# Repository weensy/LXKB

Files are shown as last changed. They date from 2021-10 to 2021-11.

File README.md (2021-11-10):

<p align="center">
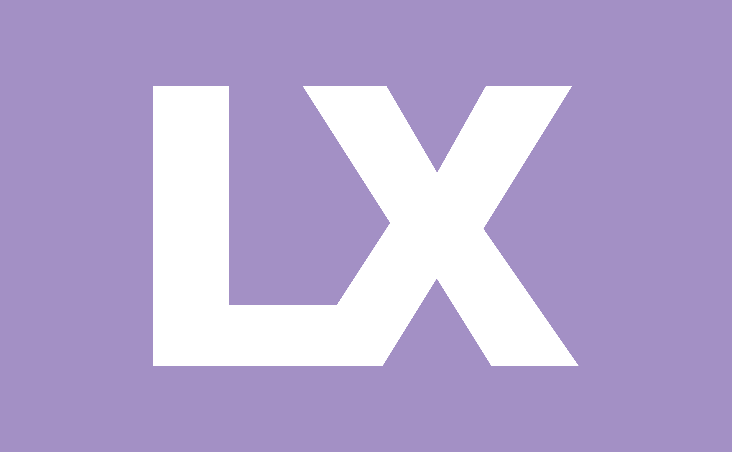
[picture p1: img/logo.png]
LXKB Logo

<p>
<h2 align="center">60% Mechanical Keyboard</h1>
  
LXKB is an open-source project that makes minimal keyboard with 60 keys.

# Introduction

### Who is it for?
For coders, writers and for everyone.  
This allows for fast typing with minimal movement.
In addition, it minimizes the burden on the shoulder even for long time use.
You should use a minimal keyboard for shoulder health.
A 60% keyboard is best for that.  
So, is LXKB different from the normal 60% keyboard?
It's in the aesthetics of this keyboard.

### Aesthetics
is realized in Symmetry.  
The following is the layout of LXKB for Windows. *[*see more layouts](layout.md)*
<p align="center">
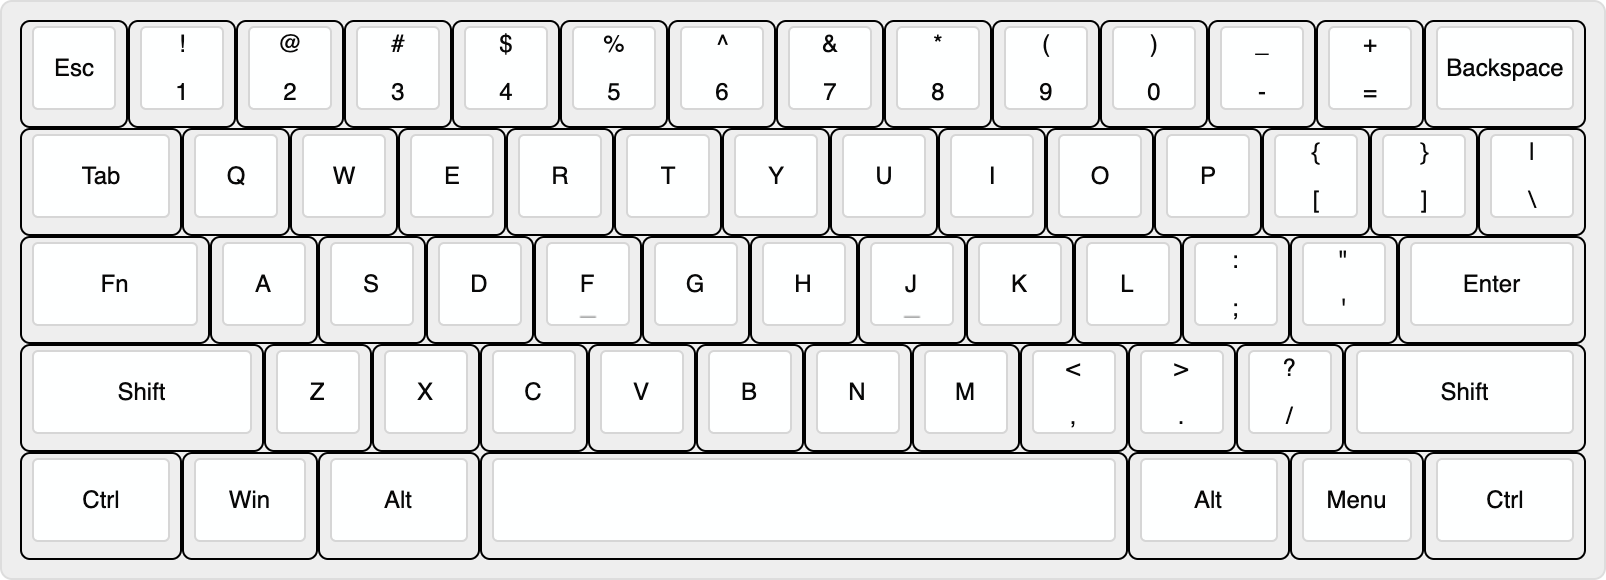
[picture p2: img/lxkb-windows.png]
LXKB for Windows

<p>

It is a completely symmetrical design.  
Draw a line in the center:
<p align="center">
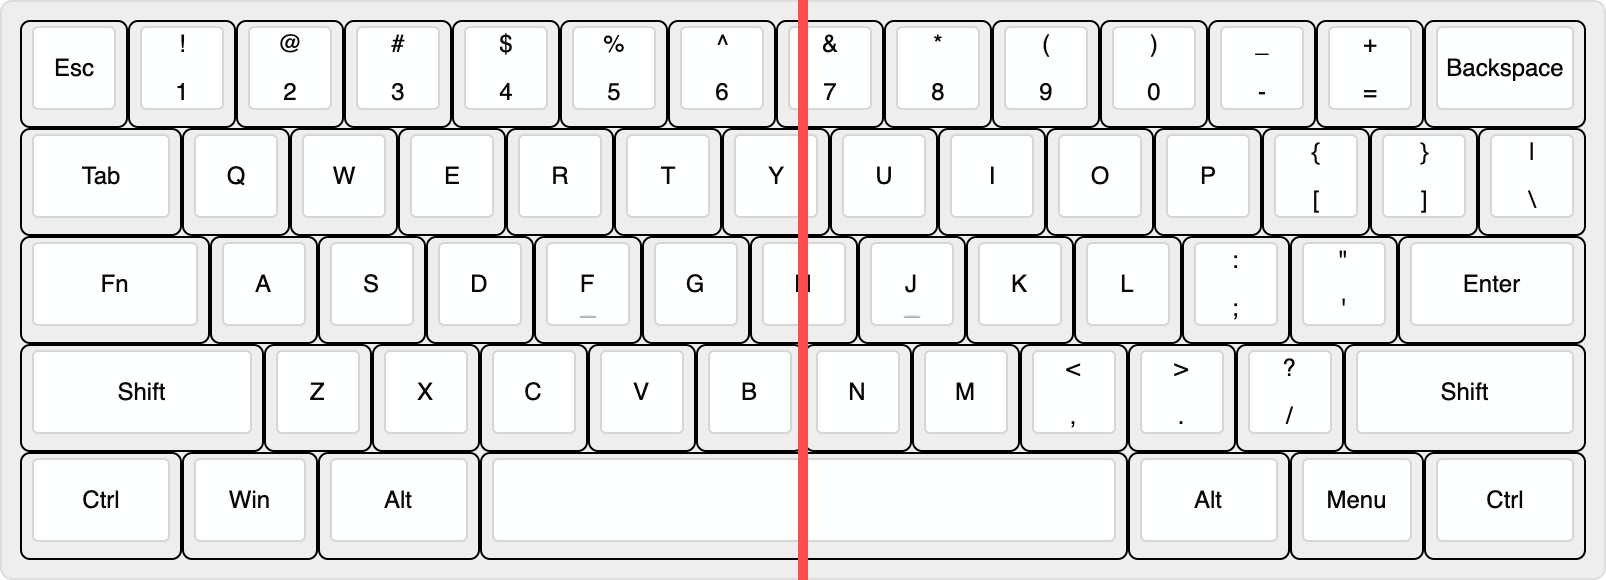
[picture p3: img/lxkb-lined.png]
LXKB center lined

<p>

Row 1, 2 are diagonally symmetric. And row 3 to 5 are perfectly symmetrical.
As is known, most people feel psychologically secure in symmetry.

### Feature
The most striking feature is the position of the Fn key.
The usage of Caps lock is very infrequent. But among the non-letter keys, it is located in the most convenient place to press. This place is a waste for Caps lock! It is why we put Fn key here.  
We have placed the rest of combination keys where comfortable to press.
People place their hands diagonally on the keyboard for body structural reasons. Therefore, the range of keys that can be pressed by moving only a finger from the default position is as follow:
<p align="center">
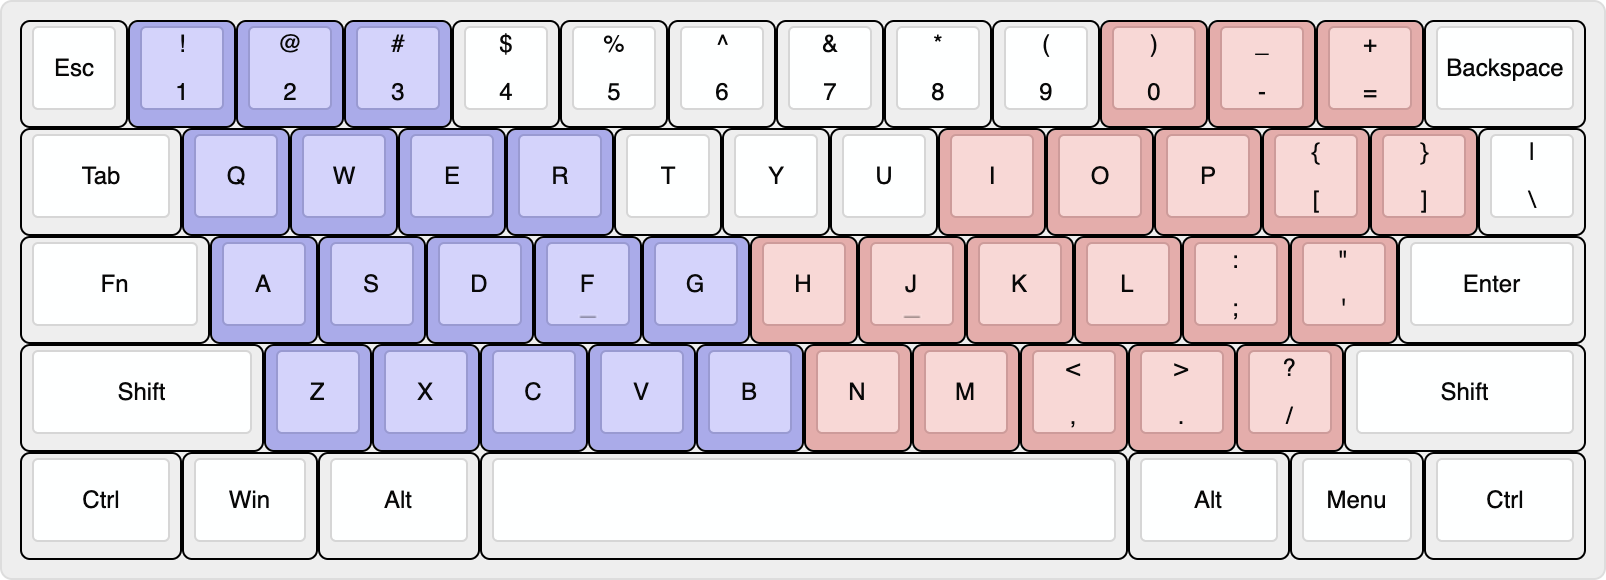
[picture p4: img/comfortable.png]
Comfortable range

<p>
Blue is left hand, red is right hand. Since the left hand presses the Fn key, the combination keys are placed in the red range. Here is the result:
<p align="center">
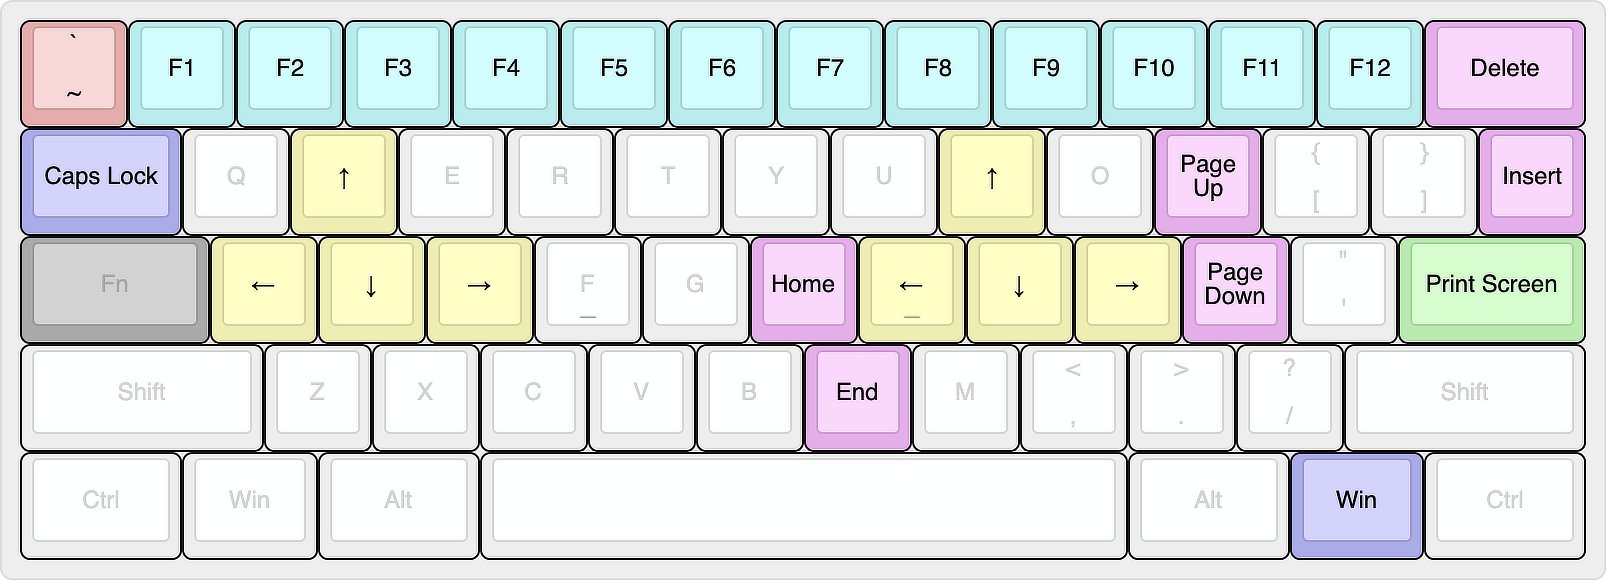
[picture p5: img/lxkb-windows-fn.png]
LXKB for Windows - Fn

<p>

### Inspired by
This layout is inspried by [these keyboards](./inspired.md).

### Keycaps
This layout is not standard, so be careful when buying keycaps.  
[Here](./keycaps.md) is a list of compatible keycap sets.

# Goals
We want to provide sources for making keyboards that is:
- Gerber files for ordering PCB
- Draw files for ordering Case
- Keymap.json file for QMK Configurator
- Documentation for ordering, assembly and setting from zero to finished product

# Contribute
Do you want to help? That’s awesome. We welcome contributions of all kinds from everyone.

# Open-source
The following open-source software was used for this project. Thanks for everything:
- [Keyboard Layout Editor](http://www.keyboard-layout-editor.com/)
- [Keyboard tools](http://keyboard-tools.xyz/)
- [Freerouting](https://github.com/freerouting/freerouting)

# License
Licensed under the [CC BY-NC-SA 4.0](./LICENSE).  
Almost everything is permitted, but not for commercial use.

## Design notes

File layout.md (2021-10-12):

# Layouts of LXKB
> These were made using [keyboard-layout-editor.com](http://www.keyboard-layout-editor.com/)

- [LXKB for Windows](http://www.keyboard-layout-editor.com/#/gists/499662763cf8b9fc48e7f24f23e9895a)
<p align="center">
LXKB for Windows
<p>

- [LXKB for Windows - Fn combined](http://www.keyboard-layout-editor.com/#/gists/9ed083197440aef61fcd359ec48cc0b2)
<p align="center">
LXKB for Windows
<p>

- [LXKB for MacOS](http://www.keyboard-layout-editor.com/#/gists/e5a1952ee05224aab8b0ef7e21352cde)
<p align="center">
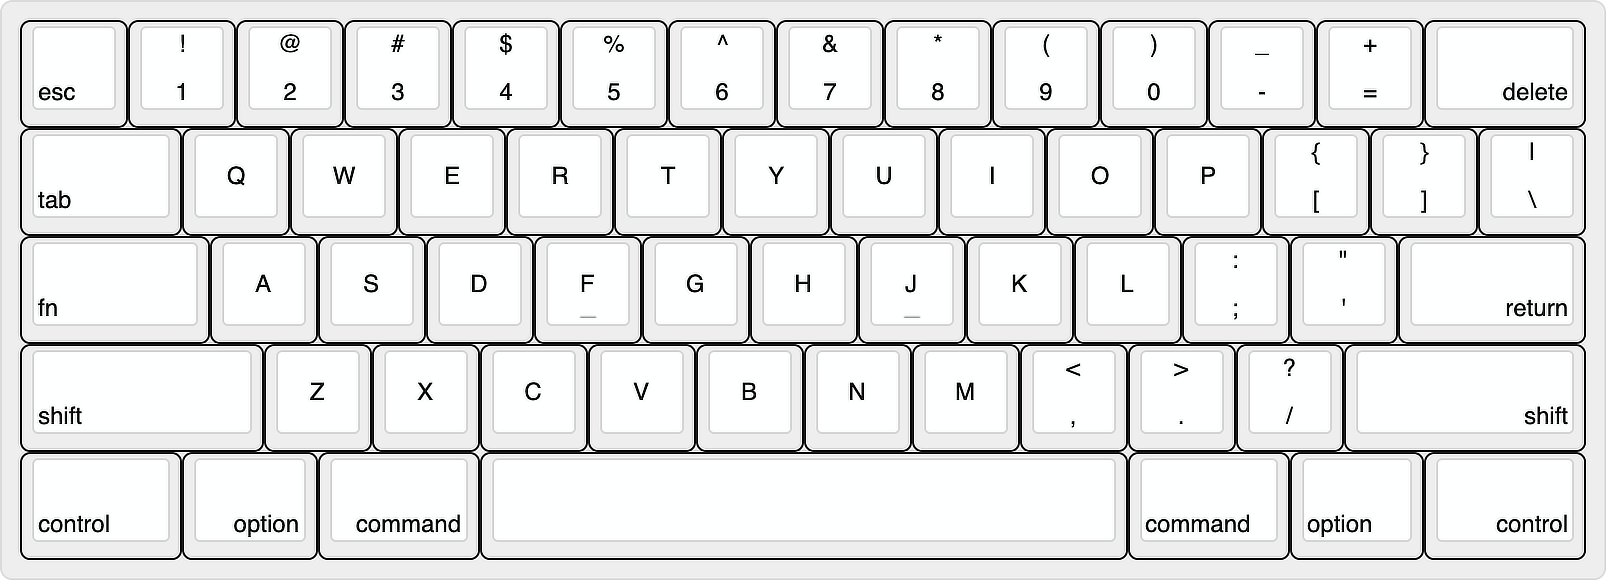
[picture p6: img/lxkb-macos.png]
LXKB for Windows

<p>

- [LXKB for MacOS - Fn combined](http://www.keyboard-layout-editor.com/#/gists/0dadb3639b67f5e03f305343836615cb)
<p align="center">
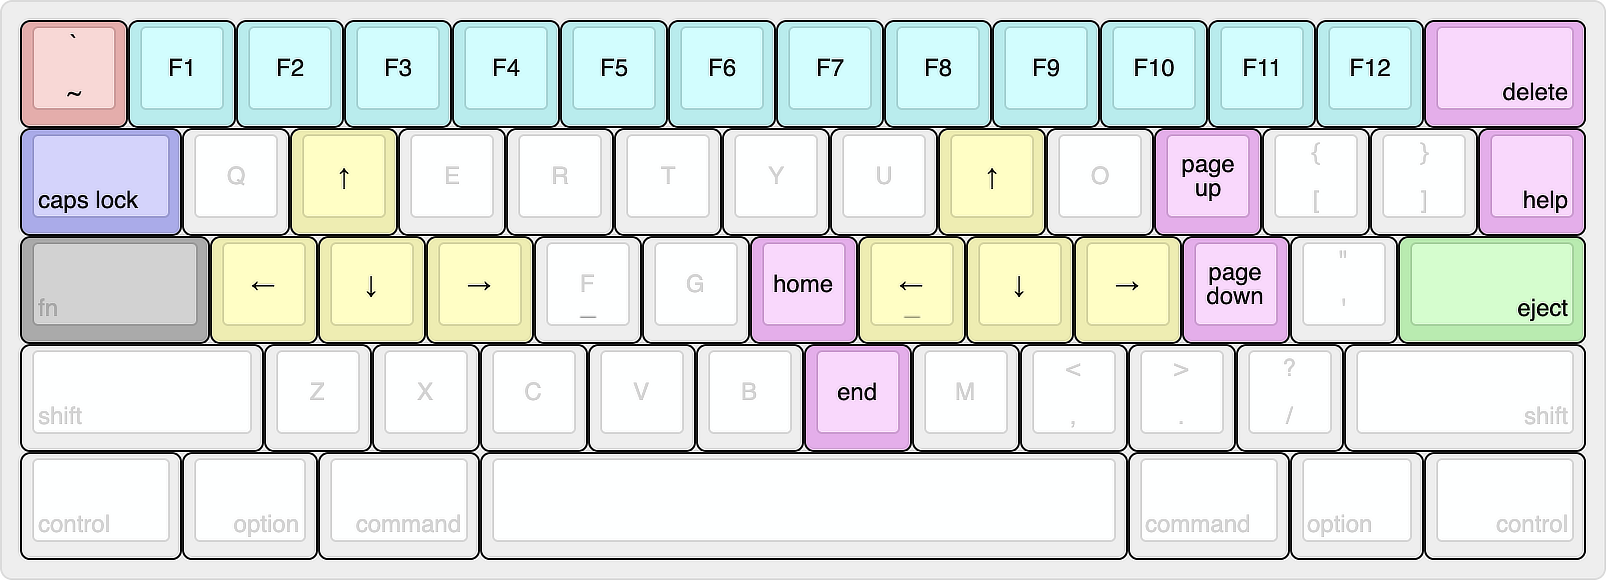
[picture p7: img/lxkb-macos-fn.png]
LXKB for Windows

<p>

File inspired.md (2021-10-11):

The LXKB's layout is inspired by old Apple keyboards.

## Apple M0110
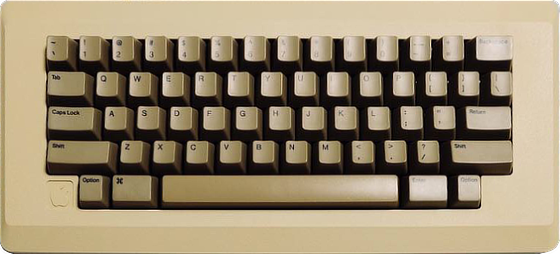
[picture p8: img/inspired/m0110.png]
M0110

- [image source](https://coolenjoy.net/bbs/34/2232320?sst=wr_hit&sod=desc&sop=and&page=4853)

## Apple M0115
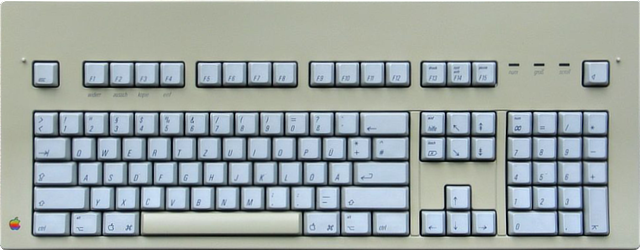
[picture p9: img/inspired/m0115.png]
M0115

- [image source](http://www.mauseum.net/Tastatura/)

## NeXT keyboard
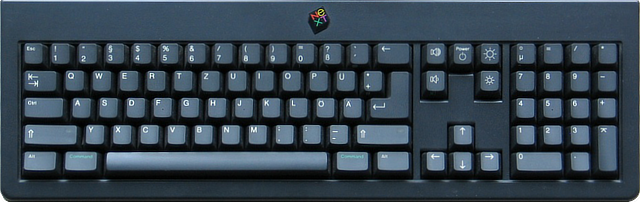
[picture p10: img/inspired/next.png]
NeXT

- [image source](http://www.mauseum.net/Tastatura/)

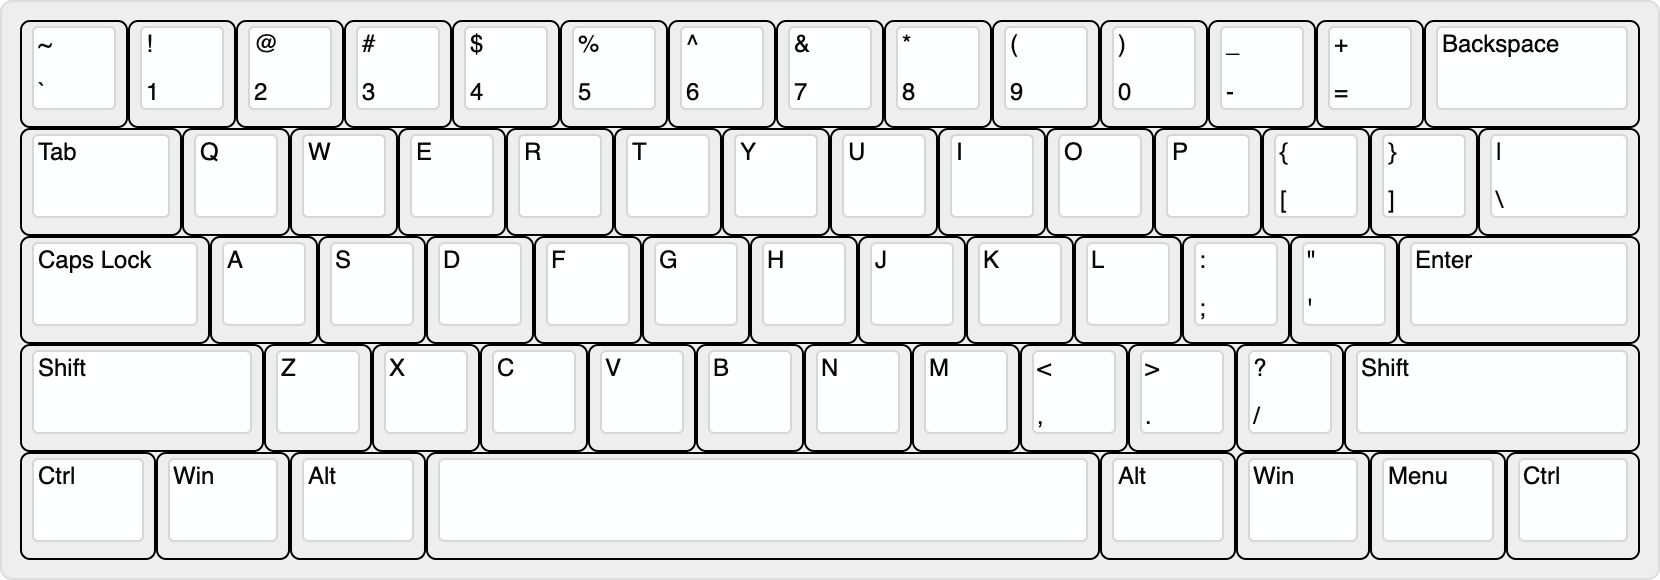
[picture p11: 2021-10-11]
img/default60.png

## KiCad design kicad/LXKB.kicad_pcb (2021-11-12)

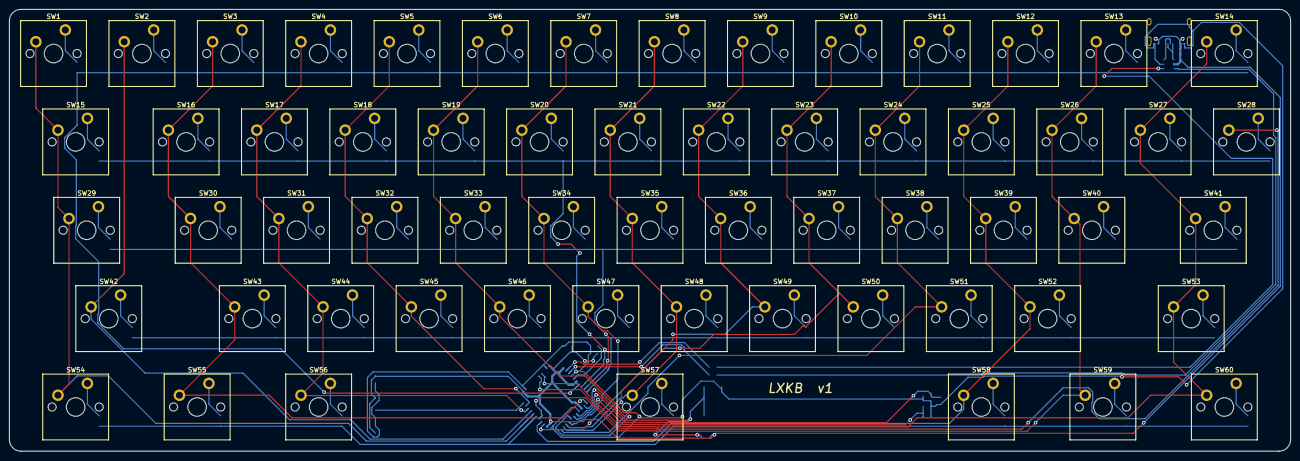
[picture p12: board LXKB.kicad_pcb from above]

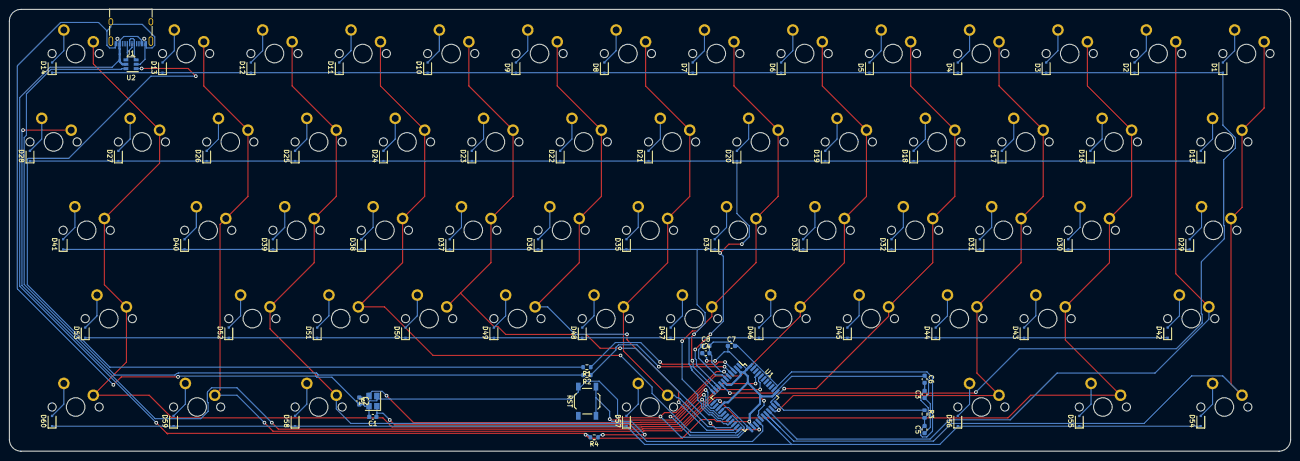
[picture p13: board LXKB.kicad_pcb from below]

Board: 2 copper layers, 276.2 x 95.2 mm, 137 parts (77 on the bottom side), 93 nets.

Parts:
C1, C2: 22p; C_0603_1608Metric
C3, C4, C5, C6: 0.1u; C_0603_1608Metric
C7: 4.7u; C_0603_1608Metric
C8: 1u; C_0603_1608Metric
D1, D2, D3, D4, D5, D6, D7, D8, D9, D10, D11, D12, D13, D14, D15, D16, D17, D18, D19, D20, D21, D22, D23, D24, D25, D26, D27, D28, D29, D30, D31, D32, D33, D34, D35, D36, D37, D38, D39, D40, D41, D42, D43, D44, D45, D46, D47, D48, D49, D50, D51, D52, D53, D54, D55, D56, D57, D58, D59, D60: D; D_SOD-323F
J1: USB_C_Receptacle_USB2.0; USB_C_Receptacle_XKB_U262-16XN-4BVC11
R1, R2: 22; R_0603_1608Metric
R3, R4: 10k; R_0603_1608Metric
RST: SW_SPST; SW_SPST_TL3342
SW1, SW2, SW3, SW4, SW5, SW6, SW7, SW8, SW9, SW10, SW11, SW12, SW13, SW16, SW17, SW18, SW19, SW20, SW21, SW22, SW23, SW24, SW25, SW26, SW27, SW28, SW30, SW31, SW32, SW33, SW34, SW35, SW36, SW37, SW38, SW39, SW40, SW43, SW44, SW45, SW46, SW47, SW48, SW49, SW50, SW51, SW52: SW_Push; SW_Cherry_MX_PCB_1.00u
SW14, SW15, SW54, SW56, SW58, SW60: SW_Push; SW_Cherry_MX_PCB_1.50u
SW29, SW41: SW_Push; SW_Cherry_MX_PCB_1.75u
SW42, SW53: SW_Push; SW_Cherry_MX_PCB_2.25u
SW55, SW59: SW_Push; SW_Cherry_MX_PCB_1.25u
SW57: SW_Push; SW_Cherry_MX_PCB_6.00u
U1: ATmega16U4-AU; TQFP-44_10x10mm_P0.8mm
U2: TPD2S017; SOT-23-6
Y1: Crystal_GND24; Crystal_SMD_3225-4Pin_3.2x2.5mm

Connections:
COL0: SW1.1, SW15.1, SW29.1, SW54.1, U1.29
COL1: SW2.1, SW42.1, U1.30
COL2: SW3.1, SW16.1, SW30.1, SW43.1, SW55.1, U1.12
COL3: SW4.1, SW17.1, SW31.1, SW44.1, SW56.1, U1.31
COL4: SW5.1, SW18.1, SW32.1, SW45.1, U1.32
COL5: SW6.1, SW19.1, SW33.1, SW46.1, U1.18
COL6: SW7.1, SW20.1, SW34.1, SW47.1, U1.19
COL7: SW8.1, SW21.1, SW35.1, SW48.1, SW57.1, U1.20
COL8: SW9.1, SW22.1, SW36.1, SW49.1, U1.21
COL9: SW10.1, SW23.1, SW37.1, SW50.1, U1.25
COL10: SW11.1, SW24.1, SW38.1, SW51.1, U1.22
COL11: SW12.1, SW25.1, SW39.1, SW52.1, SW58.1, U1.26
COL12: SW13.1, SW26.1, SW40.1, SW59.1, U1.27
COL13: SW14.1, SW27.1, SW41.1, SW53.1, SW60.1, U1.41
COL14: SW28.1, U1.40
GND: C1.2, C2.2, C3.2, C4.2, C5.2, C6.2, C7.2, C8.2, J1.A1, J1.A12, J1.B1, J1.B12, J1.S1, R3.2, RST.1, U1.5, U1.15, U1.23, U1.35, U1.43, U2.2, Y1.2, Y1.4
unnamed: D1.2, SW1.2
unnamed: D2.2, SW2.2
unnamed: D3.2, SW3.2
unnamed: D4.2, SW4.2
unnamed: D5.2, SW5.2
unnamed: D6.2, SW6.2
unnamed: D7.2, SW7.2
unnamed: D8.2, SW8.2
unnamed: D9.2, SW9.2
unnamed: D10.2, SW10.2
unnamed: D11.2, SW11.2
unnamed: D12.2, SW12.2
unnamed: D13.2, SW13.2
unnamed: D14.2, SW14.2
unnamed: D15.2, SW15.2
unnamed: D16.2, SW16.2
unnamed: D17.2, SW17.2
unnamed: D18.2, SW18.2
unnamed: D19.2, SW19.2
unnamed: D20.2, SW20.2
unnamed: D21.2, SW21.2
unnamed: D22.2, SW22.2
unnamed: D23.2, SW23.2
unnamed: D24.2, SW24.2
unnamed: D25.2, SW25.2
unnamed: D26.2, SW26.2
unnamed: D27.2, SW27.2
unnamed: D28.2, SW28.2
unnamed: D29.2, SW29.2
unnamed: D30.2, SW30.2
unnamed: D31.2, SW31.2
unnamed: D32.2, SW32.2
unnamed: D33.2, SW33.2
unnamed: D34.2, SW34.2
unnamed: D35.2, SW35.2
unnamed: D36.2, SW36.2
unnamed: D37.2, SW37.2
unnamed: D38.2, SW38.2
unnamed: D39.2, SW39.2
unnamed: D40.2, SW40.2
unnamed: D41.2, SW41.2
unnamed: D42.2, SW42.2
unnamed: D43.2, SW43.2
unnamed: D44.2, SW44.2
unnamed: D45.2, SW45.2
unnamed: D46.2, SW46.2
unnamed: D47.2, SW47.2
unnamed: D48.2, SW48.2
unnamed: D49.2, SW49.2
unnamed: D50.2, SW50.2
unnamed: D51.2, SW51.2
unnamed: D52.2, SW52.2
unnamed: D53.2, SW53.2
unnamed: D54.2, SW54.2
unnamed: D55.2, SW55.2
unnamed: D56.2, SW56.2
unnamed: D57.2, SW57.2
unnamed: D58.2, SW58.2
unnamed: D59.2, SW59.2
unnamed: D60.2, SW60.2
ROW0: D1.1, D2.1, D3.1, D4.1, D5.1, D6.1, D7.1, D8.1, D9.1, D10.1, D11.1, D12.1, D13.1, D14.1, U1.8
ROW1: D15.1, D16.1, D17.1, D18.1, D19.1, D20.1, D21.1, D22.1, D23.1, D24.1, D25.1, D26.1, D27.1, D28.1, U1.9
ROW2: D29.1, D30.1, D31.1, D32.1, D33.1, D34.1, D35.1, D36.1, D37.1, D38.1, D39.1, D40.1, D41.1, U1.10
ROW3: D42.1, D43.1, D44.1, D45.1, D46.1, D47.1, D48.1, D49.1, D50.1, D51.1, D52.1, D53.1, U1.11
ROW4: D54.1, D55.1, D56.1, D57.1, D58.1, D59.1, D60.1, U1.28
VCC: C3.1, C4.1, C5.1, C6.1, C7.1, J1.A4, J1.A9, J1.B4, J1.B9, R4.2, U1.2, U1.7, U1.14, U1.24, U1.34, U1.44, U2.5
mcu/D+: R2.1, U1.4
mcu/D-: R1.1, U1.3
mcu/UCAP: C8.1, U1.6
mcu/XTAL1: C1.1, U1.17, Y1.1
mcu/XTAL2: C2.1, U1.16, Y1.3
mcu/~HWB~/PE2: R3.1, U1.33
mcu/~RESET: R4.1, RST.2, U1.13
u2/D+: R2.2, U2.6
u2/D-: R1.2, U2.1
usb/D+: J1.A6, J1.B6, U2.4
usb/D-: J1.A7, J1.B7, U2.3

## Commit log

2021-10-13 Add KiCAD project
    [LXKB.kicad_pcb]
2021-11-10 Route PCB
    [LXKB.kicad_pcb]
2021-11-12 Add rounding to edgecut of PCB
    [LXKB.kicad_pcb]
